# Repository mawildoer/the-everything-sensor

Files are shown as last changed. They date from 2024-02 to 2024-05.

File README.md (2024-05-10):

# The Everything Sensor!

A collective dev board for all the things our hearts desired.

## Features

 - BME280 (Temperature, Humidity, Pressure)
 - LIS2DH12TR (Accelerometer)
 - TMC2209 (Stepper Motor Driver)
 - HX711 (Load Cell Amplifier)
 - ATGM336H_5N31 (GPS)
 - SGP40_D_R4 (VOC Sensor)
 - MAX31856MUDT (Thermocouple Amplifier)
 - NAU7802 (Load Cell Amplifier)
 - TCA9548APWR (I2C Multiplexer)

 AND both an RP2040 and ESP32-S2 microcontroller!

## Getting Started

The `firmware` directory uses PlatformIO to support multiple build configurations, with different scripts to test different sensors.

## Known Bugs

### `1987a17`

- The `RP2040` USB balance resistors, meant to be `27Ω`, are actually `27kΩ`. This is fixed in the dependency for later builds
- The `TCA9548APWR` reset isn't tied high. This is fixed in the dependency for later builds

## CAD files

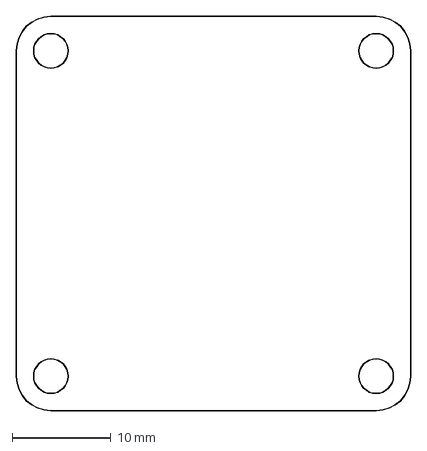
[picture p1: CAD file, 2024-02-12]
mech/template_outline.dxf
40.0 x 40.0 mm

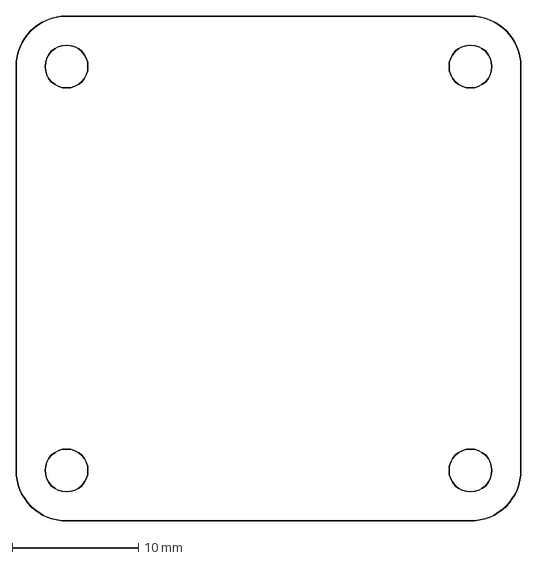
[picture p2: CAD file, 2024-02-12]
mech/template_40x40.dxf
40.0 x 40.0 mm

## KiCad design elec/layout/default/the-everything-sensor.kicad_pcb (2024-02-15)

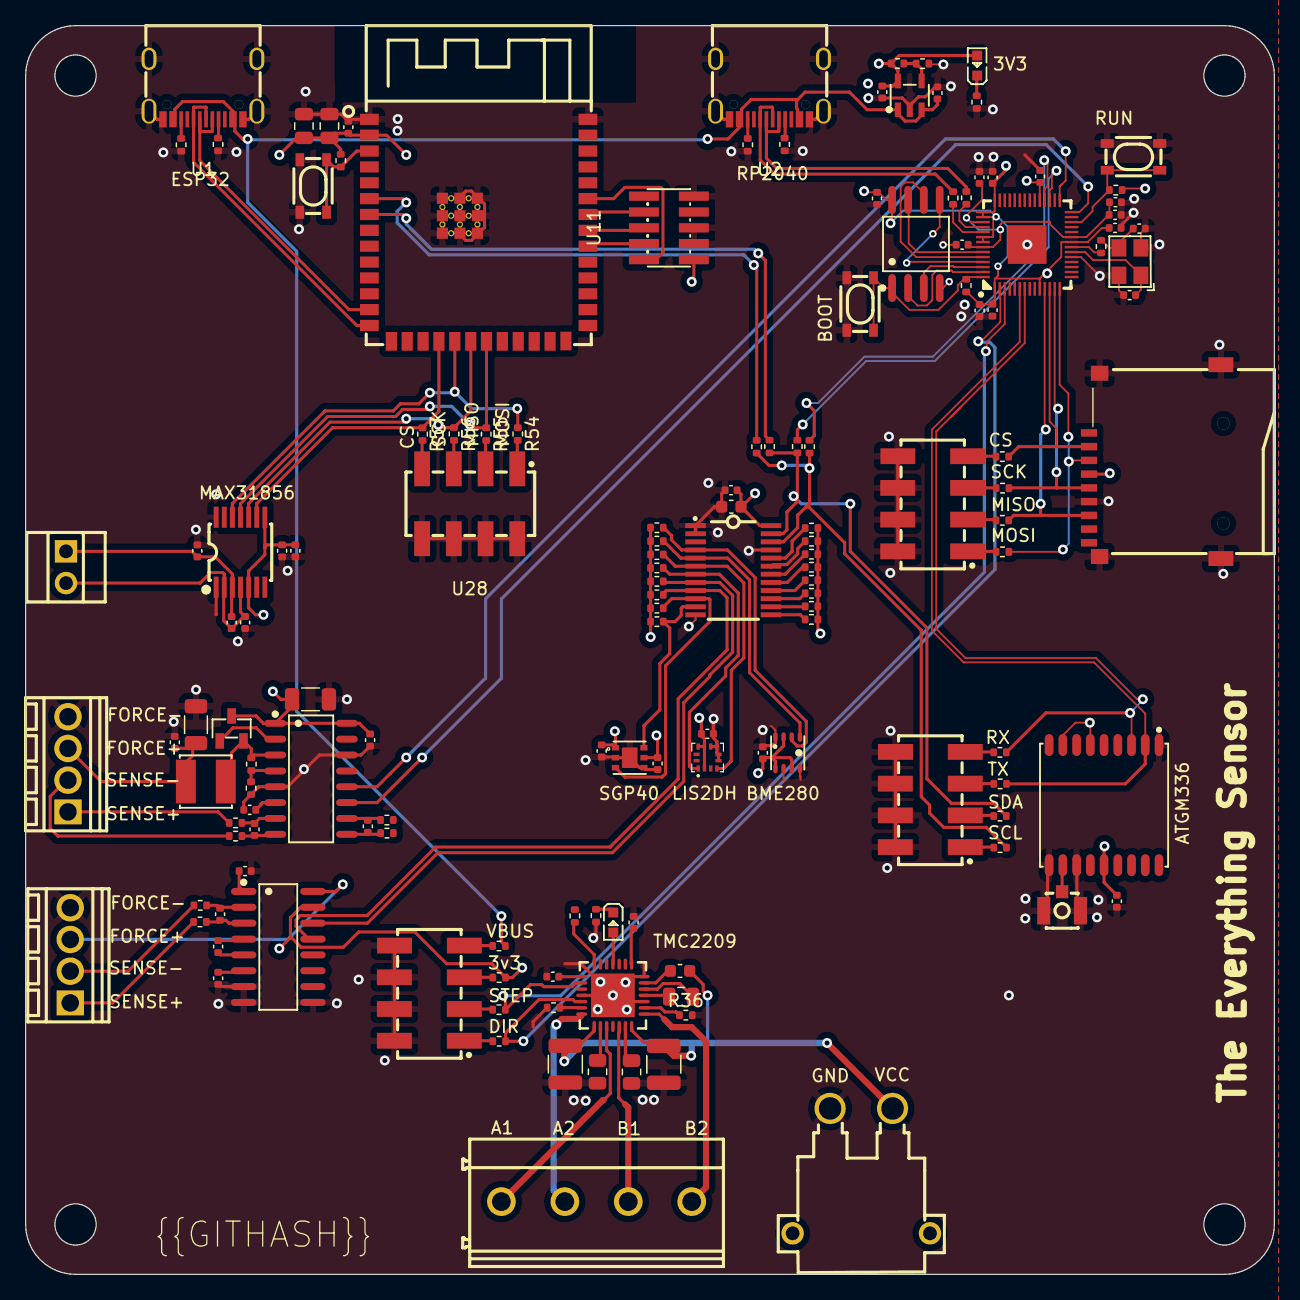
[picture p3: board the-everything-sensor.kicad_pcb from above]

Board: 4 copper layers, 100.0 x 100.0 mm, 144 parts (0 on the bottom side), 123 nets.

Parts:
C1, C3, C4, C5, C6, C7, C11, C16, C17, C18, C19, C20, C22, C23, C24, C31, C35, C36, C37, C40, C43, C44, C45, C46: Multilayer Ceramic Capacitors MLCC - SMD/SMT 100n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; C0402
C2: Multilayer Ceramic Capacitors MLCC - SMD/SMT 2.2u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; C0603
C8: Multilayer Ceramic Capacitors MLCC - SMD/SMT 270p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; C0402
C9, C10, C21, C25, C26, C27, C34: Multilayer Ceramic Capacitors MLCC - SMD/SMT 1uF 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; C0402
C12, C13: Multilayer Ceramic Capacitors MLCC - SMD/SMT 10uF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; C0805
C14, C15: Multilayer Ceramic Capacitors MLCC - SMD/SMT 20pF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; C0402
C28, C29: Multilayer Ceramic Capacitors MLCC - SMD/SMT 2.2u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; C1210
C30: Multilayer Ceramic Capacitors MLCC - SMD/SMT 2.2u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; C0402
C32: Multilayer Ceramic Capacitors MLCC - SMD/SMT 22nF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; C0805
C33: Multilayer Ceramic Capacitors MLCC - SMD/SMT 100n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; C0603
C38, C39: Multilayer Ceramic Capacitors MLCC - SMD/SMT 22nF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; C0402
C41, C42: Multilayer Ceramic Capacitors MLCC - SMD/SMT 10uF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; C1206
J1: CONN-TH_XT30PW-M
L1: 1.23A 3.3uH ±20% SMD Power Inductors ROHS; ato-04ea3db2-4b2f-45a6-9113-aa1f8beaa754
LED1, LED2: LED0603-RD
Q1: SOT-23-3_L2.9-W1.3-P1.90-LS2.4-BR
R1, R2, R3, R4: Chip Resistor - Surface Mount 4.7KOhms ±5% 1/16W 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; R0402
R5, R6, R7, R8, R9, R10, R11, R12, R13, R14, R15, R16, R17, R18, R19, R20, R30, R34: Chip Resistor - Surface Mount 10KOhms ±5% 1/16W 0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; R0402
R21, R22: Chip Resistor - Surface Mount 51Ohms ±5% 1/16W 04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; R0402
R23, R29: Chip Resistor - Surface Mount 11KOhms ±5% 1/16W 0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; R0402
R24, R25, R31, R32: Chip Resistor - Surface Mount 0Ohms ±5% 1/16W 040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; R0402
R26, R42, R43, R44, R45, R46, R47, R48, R49, R50, R51, R52, R53, R54, R55, R56, R57: Chip Resistor - Surface Mount 1KOhms ±5% 1/16W 04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; R0402
R27, R28: Chip Resistor - Surface Mount 27KOhms ±5% 1/16W 0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; R0402
R33: Chip Resistor - Surface Mount 18KOhms ±5% 1/16W 0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; R0402
R35, R38: Chip Resistor - Surface Mount 120Ohms ±5% 1/16W 0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; R0402
R36, R41: Chip Resistor - Surface Mount 110KOhms ±5% 1/16W 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; R0402
R37: Chip Resistor - Surface Mount 1.1KOhms ±5% 1/16W 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; R0402
R39, R40: Chip Resistor - Surface Mount 0.12Ohms ±5% 1/8W 0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; R0805
R58: Chip Resistor - Surface Mount 20KOhms ±5% 1/16W 0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; R0402
R59: Chip Resistor - Surface Mount 8.2KOhms ±5% 1/16W 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; R0402
R60, R61, R62, R63: Chip Resistor - Surface Mount 100Ohms ±5% 1/16W 0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; R0402
U1, U2: USB-C-SMD_KH-TYPE-C-16P
U3: TSSOP-24_L7.8-W4.4-P0.65-LS6.4-BL
U4: LGA-8_BME280_BL
U5: LGA-12_L2.0-W2.0-P0.50-BL
U6: SOP-16_L9.9-W3.9-P1.27-LS6.0-BL
U7, U30: CONN-TH_XY308-2.54-4P
U8: DFN-6_L2.4-W2.4-P0.80-TL-EP
U9: WIRELM-SMD_ESP32-S3-WROOM-1
U10, U15, U16: KEY-SMD_4P-L4.2-W3.2-P2.20-LS4.6
U11: HDR-SMD_10P-P1.27-V-M-R2-C5-LS5.3
U12: LQFN-56_L7.0-W7.0-P0.4-EP
U13: OSC-SMD_4P-L3.2-W2.5-BL
U14: SOIC-8_L5.3-W5.3-P1.27-LS8.0-BL
U17: SOT-23-5_L3.0-W1.7-P0.95-LS2.8-BL
U18: QFN-28_L5.0-W5.0-P0.50-BL-EP
U19, U22, U25, U28: HDR-SMD_8P-P2.54-V-M-R2-C4-LS7.4
U20: CONN-TH_4P-P5.08_DIBO_DB128V-5.08
U21: TF-SMD_TF-01A
U23: GPSM-SMD_ATGM336H-TR
U24: IPEX-SMD_BWIPX-1-001E
U26: TSSOP-14_L5.0-W4.4-P0.65-LS6.4-BL
U27: CONN-TH_DB125-2.54-2P-GN
U29: SOP-16_L10.0-W3.9-P1.27-LS6.0-BL

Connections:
_1: R42.2, U19.1
_1-1: R46.2, U22.1
_1-2: R50.2, U25.1
_1-3: R54.2, U28.1
_3: R43.2, U19.3
_3-1: R47.2, U22.3
_3-2: R51.2, U25.3
_3-3: R55.2, U28.3
_5: R44.2, U19.5
_5-1: R48.2, U22.5
_5-2: R52.2, U25.5
_5-3: R56.2, U28.5
_5vout: C30.1, U18.8
_7-1: R45.2, U19.7
_7-2: R49.2, U22.7
_7-3: R53.2, U25.7
_7-4: R57.2, U28.7
a1: U18.24, U20.1
a2: U18.21, U20.2
avdd: L1.1, Q1.2, R58.1, U29.3
b1: U18.26, U20.3
b2: U18.1, U20.4
base: Q1.1, U29.2
bra: R39.1, U18.23
brb: R40.1, U18.27
cathode: LED1.1, R35.1
cathode-1: LED2.1, R38.1
cc1: R1.1, U1.A5
cc1-1: R3.1, U2.A5
cc2: R2.1, U1.B5
cc2-1: R4.1, U2.B5
clock: U12.28, U29.11
cpi: C32.2, U18.5
cpo: C32.1, U18.4
cs: R57.1, U9.18, U26.9
cs-1: R30.2, U12.56, U14.1, U16.1, U16.2
cs-2: R49.1, U12.12, U21.2
data: U12.29, U29.12
diag: LED2.2, U18.11
dir: R42.1, U12.2, U18.19
dm: U1.A7, U1.B7, U9.13
dm-1: R28.1, U2.A7, U2.B7
dp: U1.A6, U1.B6, U9.14
dp-1: R27.2, U2.A6, U2.B6
en: R23.2, U9.3, U10.1, U10.2
enn: R36.1, U18.2
gnd: C1.2, C2.2, C3.2, C4.2, C6.2, C7.2, C9.2, C10.2, C11.2, C12.2, C13.2, C14.2, C15.2, C16.2, C17.2, C18.2, C19.2, C20.2, C21.2, C22.2, C23.2, C24.2, C25.2, C26.2, C27.2, C28.2, C29.2, C30.2, C31.2, C34.2, C35.2, C36.2, C38.2, C39.2, C40.2, C41.2, C42.2, C43.2, C46.2, J1.1, R1.2, R2.2, R3.2, R4.2, R34.2, R35.2, R36.2, R38.2, R39.2, R40.2, R41.2, R59.2, U1.1, U1.2, U1.3, U1.4, U1.A1, U1.A12, U1.B1, U1.B12, U2.1, U2.2, U2.3, U2.4, U2.A1, U2.A12, U2.B1, U2.B12, U3.1, U3.2, U3.12, U3.21, U4.1, U4.5, U4.7, U5.5, U5.6, U5.7, U5.8, U6.7, U6.8, U6.9, U7.4, U8.2, U8.4, U8.7, U9.1, U9.40, U9.41, U10.3, U10.4, U11.3, U11.5, U11.9, U12.19, U12.57, U13.2, U13.4, U14.4, U15.3, U15.4, U16.3, U16.4, U17.2, U18.3, U18.7, U18.18, U18.29, U19.2, U19.4, U19.6, U19.8, U21.6, U21.10, U21.11, U21.12, U21.13, U22.2, U22.4, U22.6, U22.8, U23.1, U23.10, U23.12, U24.2, U24.3, U25.2, U25.4, U25.6, U25.8, U26.1, U26.14, U28.2, U28.4, U28.6, U28.8, U29.5, U29.14, U30.4
inna: C44.2, R61.1, U29.7
innb: C45.2, R63.1, U29.9
inpa: C44.1, R60.2, U29.8
inpb: C45.1, R62.2, U29.10
io0-1: U12.53, U14.5
io1-1: U12.55, U14.2
io2-1: U12.54, U14.3
io3-1: U12.51, U14.7
miso: R55.1, U9.21, U26.11
miso-1: R47.1, U12.11, U21.7
mosi: R54.1, U9.19, U26.12
mosi-1: R46.1, U12.14, U21.3
n: R21.2, U7.2
n-1: C37.2, C39.1, U26.2, U26.4, U27.2
n-2: R60.1, U30.2
out: C15.1, R26.2, U13.3
out-1: R33.2, R34.1, U17.4
p: R22.2, U7.1
p-1: C37.1, C38.1, U26.3, U27.1
p-2: R61.2, U30.1
pdn_uart: R37.2, U18.14
refp: C7.1, U6.1
rf_in: U23.11, U24.1
run: R29.2, U12.26, U15.1, U15.2
rx: R53.1, U12.7, U23.3
sck: R56.1, U9.20, U26.10
sck-1: U12.52, U14.6
sck-2: R48.1, U12.13, U21.5
scl: R25.1, R32.1, R50.1, U3.22
scl-1: R5.2, U3.5, U4.4
scl-2: R7.2, U3.7, U5.1
scl-3: R9.2, U3.9, U6.13
scl-4: R11.2, U3.11, U8.6
scl-5: R13.2, U3.14
scl-6: R15.2, U3.16
scl-7: R17.2, U3.18
scl-8: R19.2, U3.20
scl-9: R25.2, U9.6
scl-10: R32.2, U12.32
sda: R24.1, R31.1, R51.1, U3.23
sda-1: R6.2, U3.4, U4.3
sda-2: R8.2, U3.6, U5.4
sda-3: R10.2, U3.8, U6.14
sda-4: R12.2, U3.10, U8.3
sda-5: R14.2, U3.13
sda-6: R16.2, U3.15
sda-7: R18.2, U3.17
sda-8: R20.2, U3.19
sda-9: R24.2, U9.7
sda-10: R31.2, U12.31
stdby: R41.1, U18.20
step: R43.1, U12.3, U18.16
tck: U9.32, U11.4
tdi: U9.34, U11.8
tdo: U9.33, U11.6
tms: U9.35, U11.2
tx: R52.1, U12.6, U23.2
usb_dm: R28.2, U12.46
usb_dp: R27.1, U12.47
vbg: C6.1, U6.6
vbg-1: C46.1, U29.6
vcc: C1.1, C2.1, C3.1, C4.1, C9.1, C10.1, C11.1, C12.1, C13.1, C16.1, C17.1, C18.1, C19.1, C20.1, C21.1, C27.1, C34.1, C35.1, C36.1, C40.1, C41.1, LED1.2, Q1.3, R5.1, R6.1, R7.1, R8.1, R9.1, R10.1, R11.1, R12.1, R13.1, R14.1, R15.1, R16.1, R17.1, R18.1, R19.1, R20.1, R23.1, R29.1, R30.1, R33.1, R44.1, U3.24, U4.2, U4.6, U4.8, U5.2, U5.9, U5.10, U6.15, U8.1, U8.5, U9.2, U11.1, U12.1, U12.10, U12.22, U12.33, U12.42, U12.43, U12.44, U12.48, U12.49, U14.8, U17.5, U21.4, U23.6, U23.8, U23.14, U26.5, U26.8, U29.1, U29.16
vcc-1: C26.1, R45.1, U1.A4, U1.A9, U1.B4, U1.B9, U2.A4, U2.A9, U2.B4, U2.B9, U17.1, U17.3
vcc-2: U6.16, U7.3
vcc-4: C22.1, C23.1, C24.1, C25.1, U12.23, U12.45, U12.50
vcc-5: C28.1, C29.1, C33.2, J1.2, U18.22, U18.28
vcc-6: C42.1, C43.1, L1.2, U30.3
vcc_io: C31.1, U18.15
vcp: C33.1, U18.6
vfb: R58.2, R59.1, U29.4
vin1n: C5.1, R21.1, U6.2
vin1p: C5.2, R22.1, U6.3
vin2n: C8.1, U6.4
vin2p: C8.2, U6.5
xin-1: C14.1, U12.20, U13.1
xout-1: R26.1, U12.21

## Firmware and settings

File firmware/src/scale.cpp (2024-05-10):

#include <Wire.h>

#include "SparkFun_Qwiic_Scale_NAU7802_Arduino_Library.h" // Click here to get the library: http://librarymanager/All#SparkFun_NAU7802
#include <SparkFun_I2C_Mux_Arduino_Library.h>

QWIICMUX myMux;

NAU7802 myScale; // Create instance of the NAU7802 class

void setup()
{
  Serial.begin(115200);
  Serial.println("Qwiic Scale Example");

  Wire.setPins(7, 6);
  Wire.begin();

  if (myMux.begin(0x70) == false)
  {
    while (1)
    {
      Serial.println("I2C mux not detected. Freezing...");
      delay(1000);
    }
  }

  // Port 2 is the Nau7802
  myMux.setPort(2);

  if (myScale.begin() == false)
  {
    while (1)
    {
      Serial.println("Scale not detected. Please check wiring. Freezing...");
      delay(1000);
    }
  }
  Serial.println("Scale detected!");
}

void loop()
{
  if (myScale.available() == true)
  {
    int32_t currentReading = myScale.getReading();
    Serial.print(">Reading: ");
    Serial.println(currentReading);
  }
}

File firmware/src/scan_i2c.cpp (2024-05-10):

#include <Wire.h>
#include <SparkFun_I2C_Mux_Arduino_Library.h>

QWIICMUX myMux;

void setup()
{
    Serial.begin(115200);
    delay(2000);

    Wire.setPins(7, 6);

    Serial.println();
    Serial.println("Qwiic Mux Shield Read Example");

    Wire.begin();

    if (myMux.begin(0x70) == false)
    {
        Serial.println("Mux not detected. Freezing...");
        while (1)
            ;
    }
    Serial.println("Mux detected");

    myMux.setPort(1); // Connect master to port labeled '1' on the mux

    byte currentPortNumber = myMux.getPort();
    Serial.print("CurrentPort: ");
    Serial.println(currentPortNumber);

    Serial.println("Begin scanning for I2C devices");
}

void loop()
{
    Serial.println();

    byte nDevices = 0;
    for (byte port = 1; port <= 8; port++) {
        Serial.print("Scanning port ");
        myMux.setPort(port); // Connect master to port labeled '1' on the mux
        Serial.println(port);

        for (byte address = 1; address < 127; address++)
        {
            Wire.beginTransmission(address);
            byte error = Wire.endTransmission();

            if (error == 0)
            {
                Serial.print("I2C device found at address 0x");
                if (address < 0x10)
                    Serial.print("0");
                Serial.print(address, HEX);
                Serial.println();

                nDevices++;
            }
            else if (error == 4)
            {
                Serial.print("Unknown error at address 0x");
                if (address < 0x10)
                    Serial.print("0");
                Serial.println(address, HEX);
            }
        }
    }

    if (nDevices == 0)
        Serial.println("No I2C devices found");
    else
        Serial.println("Done");

    delay(1000);
}

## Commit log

2024-02-12 Configure project
    [the-everything-sensor.kicad_pcb, the-everything-sensor.kicad_sch]
2024-02-15 layout complete
    [the-everything-sensor.kicad_pcb]
2024-02-15 cleanup silkscreen
    [the-everything-sensor.kicad_pcb]
2024-05-09 Lock the esp32 dep to where they were manufactures in 1987a17
2024-05-09 Make I2C scanner
